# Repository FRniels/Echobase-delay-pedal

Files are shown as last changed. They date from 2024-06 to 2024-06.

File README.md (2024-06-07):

# Echobase-delay-pedal

VERY IMPORTANT: In the current altium pcb design, a critical mistake was made! The positive side of C23 and C24 should be connected, if not, the PT2399 doesn't get Vcc(5V) ! Please correct this and generate new gerber files before ordering!!!
=> The schematic should be corrected (but please check it yourself if it is) but the pcb design is not corrected yet!
Others notes are found below the picture.

The Echobase. A delay pedal that can be used with instruments or other audio signals. The schematics (not designed by me, credits to the spanish designer who's name is unknown), pcb altium design, gerber files, case prototype in Fusion360 and a bill of a material for this project are available in this repository.

Echobase_pcb_and_case

Notes:
  - The speed control doesn't work. I yet have to figure out if this is a mistake on my side or it is a schematic error.
  - I would like to have the oscillation caused by the feedback potentiometer to be less responsive. At this moment is goes into self oscillation way to fast, leaving most of the potentiometer range unused.
    I think this could be fixed by replacing R19 = 20K with 39K when glancing over other existing circuits.

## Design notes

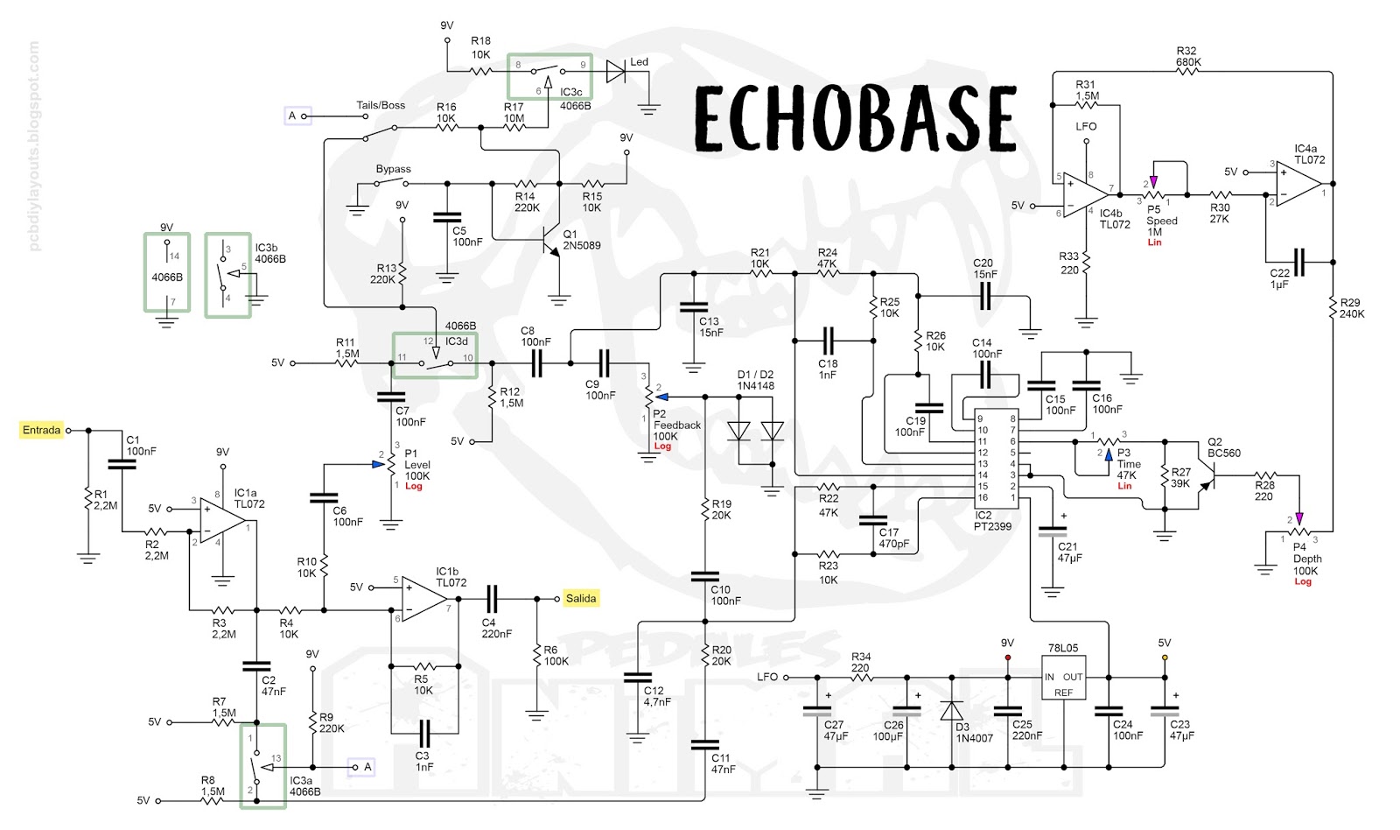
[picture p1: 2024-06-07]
Echobasesch.jpg

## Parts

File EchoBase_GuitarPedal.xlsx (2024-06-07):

Comment | Description | Designator | Footprint | LibRef | Quantity
100nF | cap 0805 V2 | C1, C5, C6, C7, C8, C9, C10, C14, C15, C16, C19, C24 | CAPC2012X94N | 0805YC103J4T2A | 12
47nF | cap 0805 V2 | C2, C11 | CAPC2012X94N | 0805YC103J4T2A | 2
1nF | cap 0805 V2 | C3, C18 | CAPC2012X94N | 0805YC103J4T2A | 2
220nF | cap 0805 V2 | C4, C25 | CAPC2012X94N | 0805YC103J4T2A | 2
4.7nF | cap 0805 V2 | C12 | CAPC2012X94N | 0805YC103J4T2A | 1
15nF | cap 0805 V2 | C13, C20 | CAPC2012X94N | 0805YC103J4T2A | 2
470pF | cap 0805 V2 | C17 | CAPC2012X94N | 0805YC103J4T2A | 1
47uF | CAP ALUM 47UF 20% 16V SMD EEEFK1C470AL panasonic | C21, C23, C27 | 47uF 16V smd EEEFK1C470AL | 47uF 16V smd EEEFK1C470AL | 3
1uF | cap 0805 V2 | C22 | CAPC2012X94N | 0805YC103J4T2A | 1
100uF | CAP ALUM 100UF 20% 16V SMD EEEFK1C101V panasonic | C26 | 100uF 16V EEEFK1C101V | 100uF 16V EEEFK1C101V | 1
1N4148 | 1N4148 - Fast Switching Diode | D1, D2 | DIOAD990W55L340D162 | 1N4148 | 2
1N4007 | 1N4007 Rectifier Diode, 1KV 1A DO-41 | D3 | DIOAD1206W86L406D200 | 1N4007 | 1
TL072CP | TL072 Dual Low-Noise JFET-Input General-Purpose Operational Amplifier | IC1, IC4 | TL072 | TL072CP IC1, TL072CP IC4 | 2
PT2399 | PT2399 Echo Processor IC | IC2 | PT2399 Echo Processor IC | PT2399 | 1
CD4066BE | CD4066BE CMOS Quad Bilateral Switch | IC3 | DIP794W53P254L1930H508Q14N | CD4066BE | 1
POWER | 2way header PCB Terminal Screw 5.08mm 16AWG 400V 13.5A 2 Position COMBICON MKDSN Series | Phoenix Contact 1729128 | J1 | PHOENIX_1729128 | 1729128 | 1
LED | 2way header PCB Terminal Screw 5.08mm 16AWG 400V 13.5A 2 Position COMBICON MKDSN Series | Phoenix Contact 1729128 | J2 | PHOENIX_1729128 | 1729128 | 1
Guitar In | 2way header PCB Terminal Screw 5.08mm 16AWG 400V 13.5A 2 Position COMBICON MKDSN Series | Phoenix Contact 1729128 | J3 | PHOENIX_1729128 | 1729128 | 1
Guitar Out | 2way header PCB Terminal Screw 5.08mm 16AWG 400V 13.5A 2 Position COMBICON MKDSN Series | Phoenix Contact 1729128 | J4 | PHOENIX_1729128 | 1729128 | 1
100K log LEVEL | HEADER, PCB, SCREW, 5.08MM, 3WAY; Connector Type: PCB; Series: MKDSN 2, 5; Connector Mounting: PCB; Pitch Spacing: 5.... | P1 | PHOENIX_MKDSN2,5/3-5.08 | MKDSN2,5/3-5.08 | 1
100K log FEEDBACK | HEADER, PCB, SCREW, 5.08MM, 3WAY; Connector Type: PCB; Series: MKDSN 2, 5; Connector Mounting: PCB; Pitch Spacing: 5.... | P2 | PHOENIX_MKDSN2,5/3-5.08 | MKDSN2,5/3-5.08 | 1
47K lin TIME | HEADER, PCB, SCREW, 5.08MM, 3WAY; Connector Type: PCB; Series: MKDSN 2, 5; Connector Mounting: PCB; Pitch Spacing: 5.... | P3 | PHOENIX_MKDSN2,5/3-5.08 | MKDSN2,5/3-5.08 | 1
100K log DEPTH | HEADER, PCB, SCREW, 5.08MM, 3WAY; Connector Type: PCB; Series: MKDSN 2, 5; Connector Mounting: PCB; Pitch Spacing: 5.... | P4 | PHOENIX_MKDSN2,5/3-5.08 | MKDSN2,5/3-5.08 | 1
1M lin SPEED | HEADER, PCB, SCREW, 5.08MM, 3WAY; Connector Type: PCB; Series: MKDSN 2, 5; Connector Mounting: PCB; Pitch Spacing: 5.... | P5 | PHOENIX_MKDSN2,5/3-5.08 | MKDSN2,5/3-5.08 | 1
2N5089 | 2N5089 => replacement BC238 BJT NPN | Q1 | 2N5089 version2 | 2N5089 version2 | 1
BC560 | BC560 BJT PNP | Q2 | BC560 | BC560 | 1
2.2M | Resistor 0805 | R1, R2, R3 | RESC2013X65N | CRGH0805J47K | 3
10K | Resistor 0805 | R4, R5, R10, R15, R16, R18, R21, R23, R25, R26 | RESC2013X65N | CRGH0805J47K | 10
100K | Resistor 0805 | R6 | RESC2013X65N | CRGH0805J47K | 1
1.5M | Resistor 0805 | R7, R8, R11, R12, R31 | RESC2013X65N | CRGH0805J47K | 5
220K | Resistor 0805 | R9, R13, R14 | RESC2013X65N | CRGH0805J47K | 3
10M | Resistor 0805 | R17 | RESC2013X65N | CRGH0805J47K | 1
20K | Resistor 0805 | R19, R20 | RESC2013X65N | CRGH0805J47K | 2
47K | Resistor 0805 | R22, R24 | RESC2013X65N | CRGH0805J47K | 2
39K | Resistor 0805 | R27 | RESC2013X65N | CRGH0805J47K | 1
220E | Resistor 0805 | R28, R33, R34 | RESC2013X65N | CRGH0805J47K | 3
240K | Resistor 0805 | R29 | RESC2013X65N | CRGH0805J47K | 1
27K | Resistor 0805 | R30 | RESC2013X65N | CRGH0805J47K | 1
680K | Resistor 0805 | R32 | RESC2013X65N | CRGH0805J47K | 1
BYPASS | 2way header PCB Terminal Screw 5.08mm 16AWG 400V 13.5A 2 Position COMBICON MKDSN Series | Phoenix Contact 1729128 | SW1 | PHOENIX_1729128 | 1729128 | 1
Tails/Boss | HEADER, PCB, SCREW, 5.08MM, 3WAY; Connector Type: PCB; Series: MKDSN 2, 5; Connector Mounting: PCB; Pitch Spacing: 5.... | SW2 | PHOENIX_MKDSN2,5/3-5.08 | MKDSN2,5/3-5.08 | 1
LM7805 | LM7805 max 35V to 5.5V POSITIVE VOLTAGE REGULATOR TO 220 M | U1 | TO254P470X990X1900-3P | LM7805 | 1

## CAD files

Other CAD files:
Echobase case v1.f3d

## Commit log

2024-06-07 Add files via upload
    Added the circuit schematics.
2024-06-07 Add files via upload
    Added the case prototype created in Fusion360.
    Note:
    This design needs to be adjusted to be able to close the bottom plate.
    The case should be enlarged and little blocks with a screw hole should be added in the corners of the case
    so that the bottom plate can be screwed into these blocks..
    [Echobase case v1.f3d]
2024-06-07 Add files via upload
    Added the Altium pcb design files and libraries, gerber files and drill hole files.
    Note to find the files in the zip file: The zip file contains the same folder structure as the default altium folder structure.
2024-06-07 Add files via upload
    Added the bill of material.
    Component list for now: actual prices will follow in future commit.
    [EchoBase_GuitarPedal.xlsx]
2024-06-07 Update README.md
    Added a picture of the pcb and case to the readme
